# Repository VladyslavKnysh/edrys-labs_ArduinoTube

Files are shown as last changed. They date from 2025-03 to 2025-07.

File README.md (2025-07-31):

# edrys-labs Arduino Tube

This online lab demonstrates a control system that uses an Arduino-based setup to levitate a ball in the air and maintain its position using a PID (Proportional-Integral-Derivative) controller. The system involves a fan that adjusts its output based on feedback from a laser sensor, allowing the ball to remain suspended at a set height. Students can interact with the system remotely, programming their own PID controller in real time to observe the effects on system stability, responsiveness, and accuracy. The lab offers hands-on experience in control theory and real-world PID implementation.

## Apperance
The appearance of the system can be seen in the photo below. A transparent PVC pipe 1 m long and a laboratory stand were used to create the frame of the system. The mounts were printed on a 3D printer. All STL files are located in the \stl\ folder.

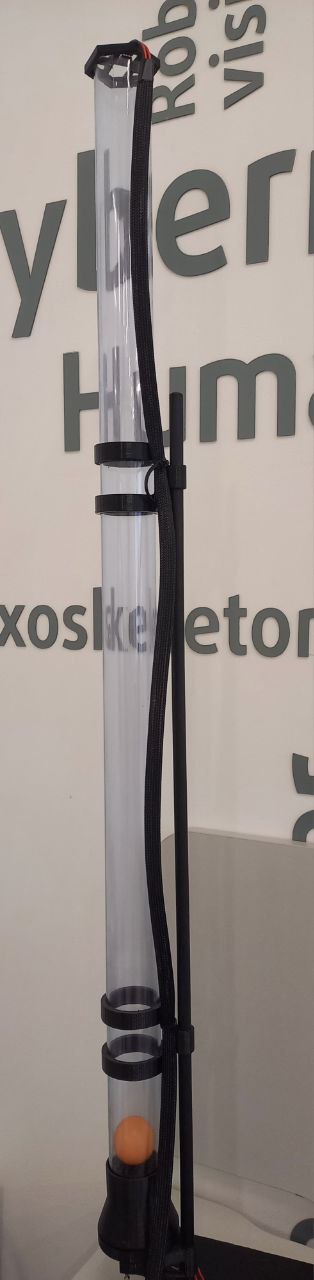
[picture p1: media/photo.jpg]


## Code
The sample code can be found in the file example.ino .

## BOM
To build similar laboratory equipment next items: 

| Component | Used in example | Substitution | Function |
| :---:|:---:| :---| :---|
| MCU | ArduinoNano | Any Arduino or ESP board with 5V logic level and PWM functions | Controls the whole system + connects with the terminal |
| Transistor | IRF520 | Any N-chanel MOSFET with low enough Vgs | Controls power supply of a motor |
| Diode | SF26 | Any fast diode | Electrical protection |
| Laser-ranging module | VL53L0X | Any similar module | Measures the position of the ball |
| Motor | 50000RPM drone motor | Any similar high-speed DC motor | Creates an air flow |
| Ball | Ping-pong ball | One and only | Acts as a liftable object |
| Cam | USB web-cam | Any USB web-cam | Shows the expirement to the whole wide world |
| Power Supply | 5V 2A DC PS | PS unit that meets the requirements of your system | Powers the whole system |

It should be noted that the thrust of the system greatly depends on the motor parameters, i.e., a more powerful motor will require lower coefficients and vice versa.

## Schematic
You can see the full electrical schematil on the picture lower:

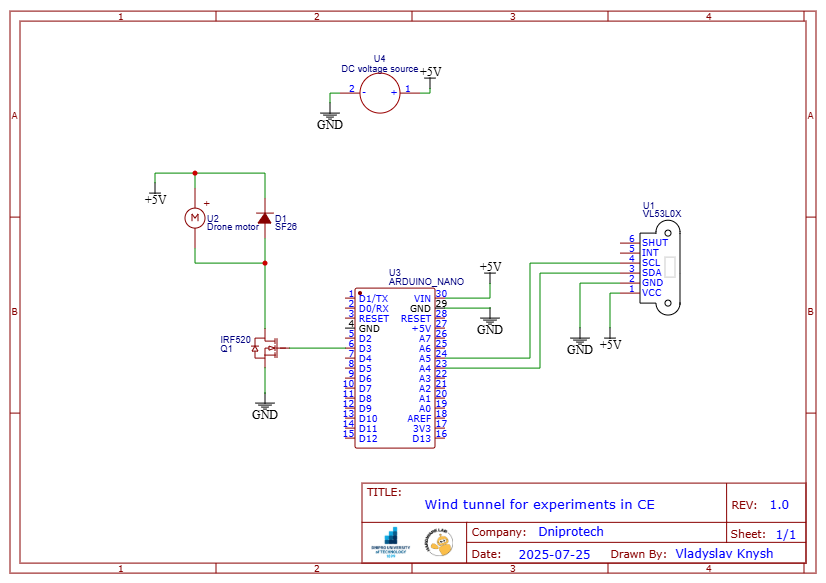
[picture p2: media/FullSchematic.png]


## Video Presentation

<video width="630" height="300" src="https://github.com/user-attachments/assets/e87ab2ab-11ce-4c1f-ad92-d0ffda92d6e0"></video>

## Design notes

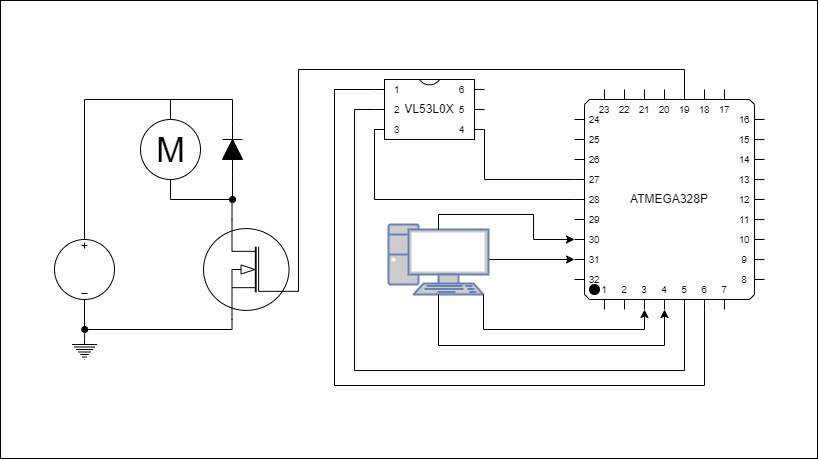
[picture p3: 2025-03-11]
media/TubeSchematic.png

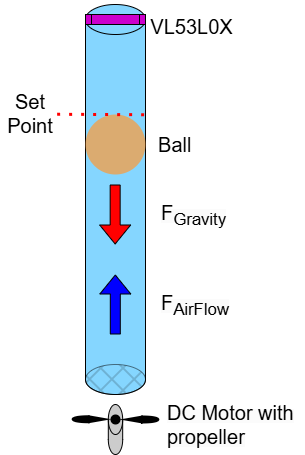
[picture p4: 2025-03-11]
media/TUBE.drawing.png

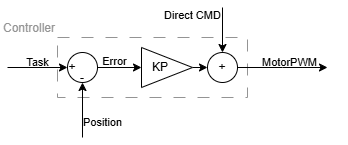
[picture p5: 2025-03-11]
media/TubeFR_P.png

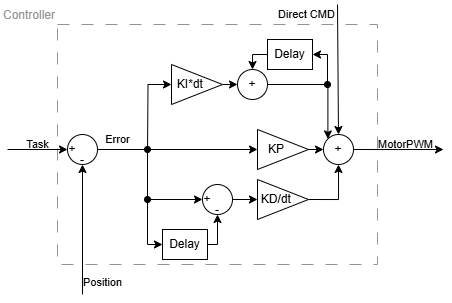
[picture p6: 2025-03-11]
media/TubeFR_PID.png

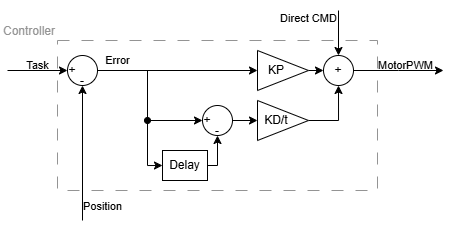
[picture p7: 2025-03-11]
media/TubeFR_PD.png

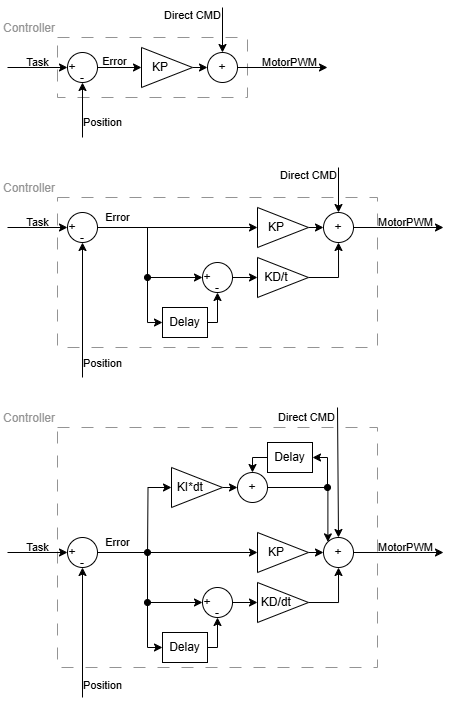
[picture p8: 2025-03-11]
media/TubeFR.png

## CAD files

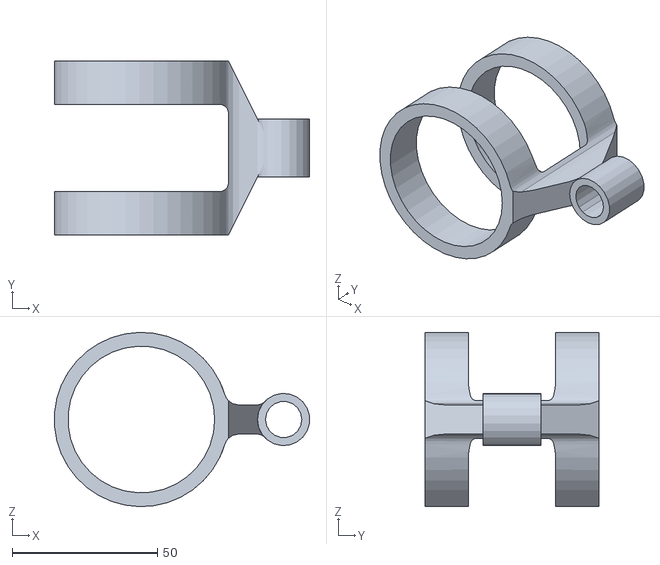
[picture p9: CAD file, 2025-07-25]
stl/mount.stl
87.8 x 60.0 x 60.0

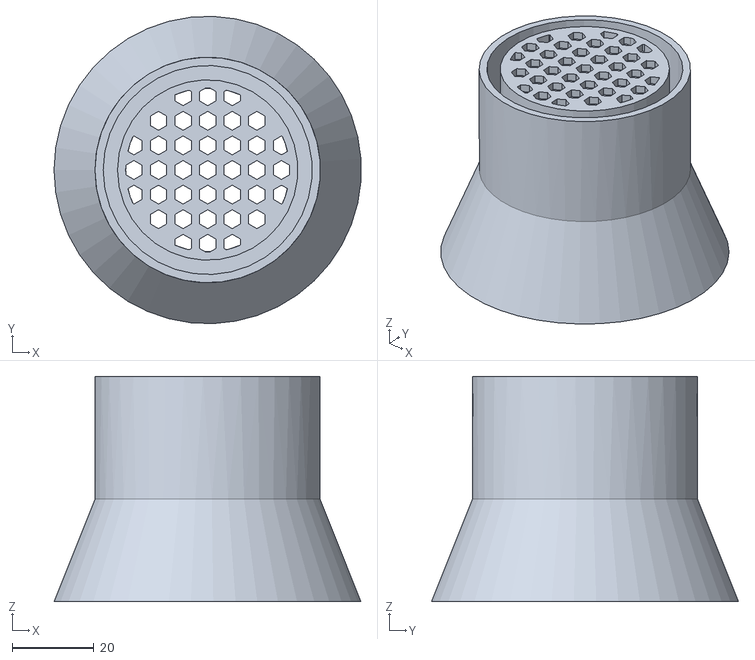
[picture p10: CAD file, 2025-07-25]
stl/baseMountPart1.stl
74.9 x 74.9 x 55.0

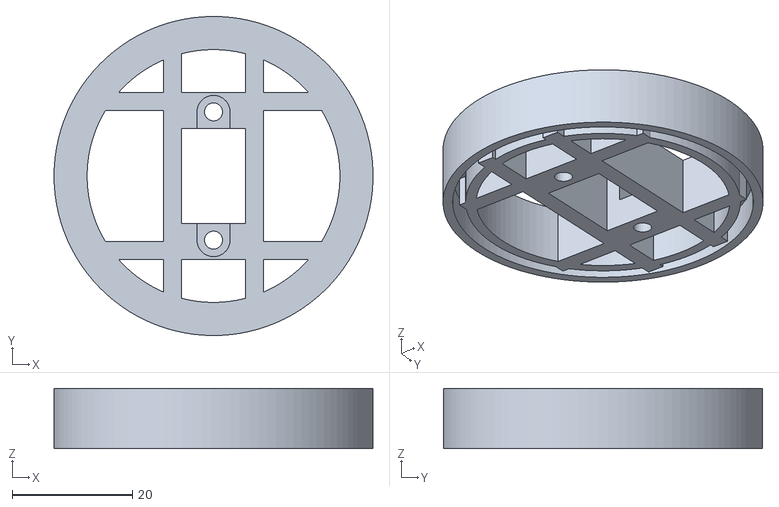
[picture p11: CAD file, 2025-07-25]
stl/tubeCap.stl
53.0 x 53.0 x 10.0

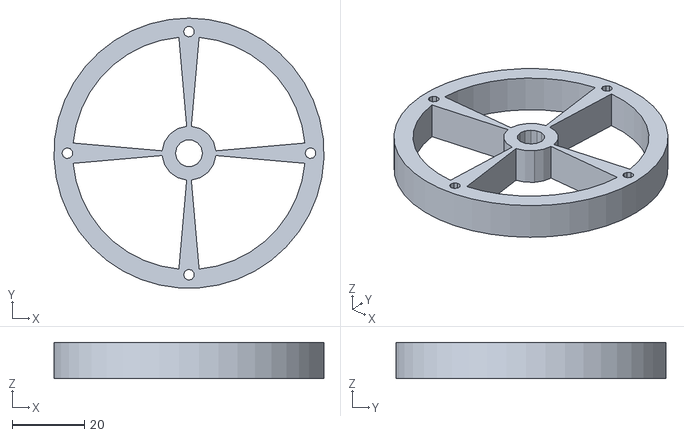
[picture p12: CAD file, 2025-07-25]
stl/baseMountPart2.stl
74.9 x 74.9 x 10.0

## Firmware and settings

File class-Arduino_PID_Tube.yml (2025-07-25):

id: VVFzgyp4Rns9TMXY
createdBy: MHhLOiC6Lbr0
dateCreated: 1689064662293
name: Arduino - PID Tube
meta:
  logo: >-
    https://raw.githubusercontent.com/VladyslavKnysh/edrys-labs_PIDtube/refs/heads/main/media/TUBE.drawing.png
  description: >+
    This online lab demonstrates a control system that uses an Arduino-based
    setup to levitate a ball in the air and maintain its position using a PID
    (Proportional-Integral-Derivative) controller. The system involves a fan
    that adjusts its output based on feedback from a laser sensor, allowing the
    ball to remain suspended at a set height. Students can interact with the
    system remotely, programming their own PID controller in real time to
    observe the effects on system stability, responsiveness, and accuracy. The
    lab offers hands-on experience in control theory and real-world PID
    implementation.

  selfAssign: true
  defaultNumberOfRooms: '0'
  id: 79sFHo6ONB1S25cTN7emXmOibQ2HNWb2G9X3Xn2x
members:
  teacher:
    - BrzW9fREmtys
    - fF6qHw6EaHrr
  student: []
modules:
  - url: https://edrys-labs.github.io/module-markdown-it/index.html
    config:
      content: >-
        # Introduction to proportional–integral–derivative controller


        ## PID controller


        Machines and processes that need constant management and automated
        modification are frequently managed with a feedback-based control loop
        mechanism called a proportional-integral-derivative (PID) controller.
         - The present set point (SP) − process variable (PV) error value is proportional to term P.
         - Term I generates the I term by integrating the past values of the SP − PV error over time.
         - Term D is the best estimate of the SP − PV error's future trend.
         
         ## Hardware
         
         In this experiment the motor with propeller is used to create air flow that will overcome the gravitation and rise the ball up into the air to the set point level inside an aerodynamic tune. 
         On the picture bellow is showed hardware scheme of the experiment.
         
         <img src ="https://raw.githubusercontent.com/VladyslavKnysh/edrys-labs_PIDtube/refs/heads/main/media/TubeSchematic.png" alt="Hardware scheme"  width="666" height="800">
         <img src ="https://raw.githubusercontent.com/VladyslavKnysh/edrys-labs_PIDtube/refs/heads/main/media/TUBE.drawing.png" alt="Tube scheme"  width="250" height="300">
         
         ## Assignment
         
         In this experiment students are tasked with controlling the affromentioned tube system. The expeiment is separeted into 4 parts:
         - Direct controll 
         - P + direct controll 
         - PD + direct controll 
         - PID + direct controll
    studentConfig:
      content: ''
    teacherConfig:
      content: ''
    stationConfig:
      content: ''
    showInCustom: lobby
    width: 1920
    height: 1080
  - url: https://edrys-labs.github.io/module-markdown-it/index.html
    config:
      content: >-
        # Proportional–integral–derivative controller

        ## Step 1: Direct control of the motor


        **Objective**: To find the coefficient of direct control.


        1. **Prepare the sketch**:

            - Write the primary sketch that will help you use PWM of the Arduino`s D3 pin to controll the motor speed.
             
        2. **Find the coefficient**:

            - There are two main possible roots of performing this task: 
               a) You can start from 0 and gradually increase the pwm value until the ball almost rises up into the air;
               b) Or you can start from the 255 and gradually decrease the pwm value until the ball almost rises up into the air;

        3. **Write down the result**: 

            - Write down the coefficient that was found. It will be used in the next tests.

        ## Step 2: Proportional controller


        **Objective**: To program the algorithm of the Proportional controller.
        and to find the KP value with low steady state error.

          <img src="https://raw.githubusercontent.com/VladyslavKnysh/edrys-labs_PIDtube/refs/heads/main/media/TubeFR_P.png" alt="P scheme">

        1. **Modify Your Code**:

            - Add the following lines to enable laser-ranging module VL53L0X:

               ```cpp
              #include <Wire.h>
              #include <VL53L0X.h>
            
              VL53L0X sensor;
            
                //Enter your global variables here
            
              // the setup function runs once when you press reset or power the board
              void setup() {
                Serial.begin(9600);
                Wire.begin();
            
                sensor.setTimeout(500);
                if (!sensor.init())
                {
                  Serial.println("Failed to detect and initialize sensor!");
                  while (1) {}
                }
               ```

        2. **Make motorCMD dynamic**:
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

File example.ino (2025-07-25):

#include <Wire.h>
#include <VL53L0X.h>

VL53L0X sensor;

double kp = 0.002;
double ki = 0.001;
double kd = 0.0003;
int dir   = 166; 

double KP,KI,KD;

int motorCMD, errorValue, prevErrorValue;

double sum, prevSum;

int motorPin = 3;

unsigned long tic, tic2, tic3;
int pause = 100;
int steadiness = 5000/pause;

void setup() {
  // put your setup code here, to run once:
  Serial.begin(9600);

  pinMode(motorPin, OUTPUT);

  Wire.begin();

  if (!sensor.init())
  {
    Serial.println("Failed to detect and initialize sensor!");
    while (1) {}
  }

  sensor.startContinuous();
  Serial.println("Write your task:");
}

void loop() {
  // put your main code here, to run repeatedly:
  if(Serial.available()>0){
    int pos, i,j;
    int task = Serial.parseInt();
    if(task>0){
      tic = millis();
      while(millis()<tic+30000){
        tic2 = millis();
        pos = 970 - sensor.readRangeContinuousMillimeters();
        errorValue = task - pos;
        sum = prevSum+pause*ki*errorValue/1000;
        
        KP = kp*errorValue*255;
        KI = sum*255;
        KD = ((errorValue-prevErrorValue)/(i*1000/pause))*kd*255;

         motorCMD = dir+KP+KI+KD;

         if(motorCMD>255){
           motorCMD = 255;
         }else if(motorCMD<0){
           motorCMD = 0;
         }
         analogWrite(motorPin,motorCMD);
        
        if(abs(errorValue)<20){
          j++;
        }else{
          j=0;
        }
        if(j>=steadiness){
          break;
        }
        
        Serial.print("Position:");
        Serial.println(pos);

        prevErrorValue = errorValue;
        prevSum = sum;
        i++;
        delay(tic2+pause-millis());
      }
        double grad = motorCMD/5;
        tic3 = millis();
        while(tic3+5000>millis()){
             analogWrite(motorPin,motorCMD - grad*millis()/1000);
        }
         analogWrite(motorPin,0);
    }
    Serial.println("Write your task:");
  }
  
}

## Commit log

2025-03-11 Add files via upload
    Added tube schematic.png
2025-07-25 added share files
    [class_arduino_PID_Tube.json, class_arduino_PID_Tube.yml]
2025-07-25 added full schematic
2025-07-25 added STLs
    [baseMountPart1.stl, baseMountPart2.stl, mount.stl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]
